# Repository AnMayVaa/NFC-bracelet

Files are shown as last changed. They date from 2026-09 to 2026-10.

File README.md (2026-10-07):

# 🍊 Jeju wish-band: Travel + Connect + Protect

A smart basalt-bead wristband for Jeju visitors. Tap the band on a phone to open a personal travel app with **AI picks** for local food, hidden places and activities. Tap it at wish-band stations to collect stamps and leave a **last-known location** for safety. The **Helping Map** and **SOS** button connect tourists to help, and the admin desk sees everything live.

| Part | What it does |
| :--- | :--- |
| 📱 Tourist app (`/<UID>`) | **For You**: one-tap diet setup, stamp progress strip, live weather card, map + AI picks (diet-safe, weather-aware, boosts local and quiet spots) · **Stamps**: road route map, passport, 4,000 KRW Dongmun Market voucher · **SOS**: hold-to-send SOS, Korean hotlines, your embassy or consulate, Helping Map, help near you · **Me**: any nationality (flag, name in any script), international emergency contact, language (English, 한국어, 中文, 日本語, ไทย) and dark mode |
| 🏢 Admin desk (`/admin`) | Issue and register bands, write NFC tags, SOS queue (acknowledge, dispatch, resolve), station health, live log, evaluation metrics, **Demo control** (load a mock story, play each journey step for one band, clear SOS / stamps / guests, download a backup, delete everything) |
| 📟 `firmware/admin` | ESP32 + PN532 desk reader: reads the tag, writes the tourist link, reports to the admin desk |
| 🍊 `firmware/food` · 🗿 `firmware/place` · 🌊 `firmware/activity` | ESP32 stations (MFRC522 by default, PN532 optional): each tap gives a stamp of that kind |

---

## 1. Run it

```bash
npm install
npm start            # http://localhost:3000
npm test             # core rules: stamps, voucher, diet filter, SOS flow, migration
```

- Tourist app: http://localhost:3000/BEAD_001 (any tag UID works as the path)
- Admin desk: http://localhost:3000/admin, then press **Load full demo story** in Demo control
- Live site: https://smart-nfc-bracelet.vercel.app (Vercel uses `api/index.js`)

To simulate taps without hardware, use **Demo control** on the admin desk (`/admin`).

### Environment variables (all optional)

| Variable | Default | Meaning |
| :--- | :--- | :--- |
| `PUBLIC_URL` | `https://smart-nfc-bracelet.vercel.app` | Base of the link written onto tags |
| `MERCHANT_PIN` | `4000` | PIN the market vendor types to redeem a voucher |
| `STATION_KEY` | empty | If set, ESP32s must send it as `X-Station-Key` (put the same value in `secrets.h`) |
| `ADMIN_PIN` | empty | If set, the admin desk asks for it |
| `DEMO_MODE` | `true` | `false` hides demo tools, Demo control, simulated taps, wipe and restore |
| `UV_OVERRIDE` | empty | Force a UV index (for demos); otherwise live UV from Open-Meteo |
| `WEATHER_OVERRIDE` | empty | Force weather for a demo, e.g. `{"tempC":24,"rainChance":90,"precipMm":3}` |
| `PHOTOS_LIVE` | on | `0` stops the live Wikipedia photo lookup (cards keep their emoji unless photos are bundled) |
| `OSRM_URL` | OpenStreetMap foot router | Routing server for the road route on the Stamps map |
| `SUPABASE_URL` | empty | Your Supabase project URL. With the key below, data lives in Supabase instead of `database.json` |
| `SUPABASE_SERVICE_ROLE_KEY` | empty | Supabase secret key (server only, never in the browser or in git) |

### Database: Supabase (recommended for Vercel)

Without the two Supabase variables the app keeps everything in `database.json` (on Vercel that is `/tmp`, which resets). With them, every wish-band, stamp and SOS alert is saved in Supabase Postgres, shared by all Vercel instances, and you can check it in the Supabase **Table Editor**.

1. Create a free project at [supabase.com](https://supabase.com) (region: Seoul or Singapore).
2. **SQL Editor → New query**, paste [`supabase/schema.sql`](supabase/schema.sql), press **Run**. This creates the `tourists` and `sos_alerts` tables plus read-only views `checkins`, `location_log` and `recommendation_events`.
3. **Project Settings → API**: copy the **Project URL** and the **service_role** (secret) key.
4. **Vercel → smart-nfc-bracelet → Settings → Environment Variables**: add `SUPABASE_URL` and `SUPABASE_SERVICE_ROLE_KEY`, then redeploy. For local runs put them in your shell before `npm start`.
5. Open `/api/health`: it shows `"storage": "supabase"` and `"database": { "ok": true, "tourists": N }` when it is connected, or the Supabase error message if not. On /admin, **Demo control → Load full demo story** fills the tables with 11 demo wish-bands and 3 SOS alerts; the header chip turns green ("Supabase").

Row Level Security is on with no policies, so the public anon key can read nothing; only the server's secret key can. Never commit the secret key (the repo is public).

---

## 2. Project structure

```
lib/
  core.js            business rules (pure functions, unit tested)
  app.js             every API route, shared by both servers
  store.js           Supabase or JSON-file store, schema version + auto-migration
  weather.js         live Jeju weather: UV, temperature, rain, wind (Open-Meteo, cached 15 min)
  route.js           Stamps route along real roads (saved file, OSRM, or straight lines)
  photos.js          real photos for the For You cards (bundled file, else Wikipedia/Commons live)
  data/countries.js  calling codes for every country (names come from the browser in any language)
  data/stations.js   stations, stamp kinds, reward rule, help points, hotlines
  data/catalog.js    places / food / activities the AI picks from
server.js            local server: shared app + static files + WebSocket
api/index.js         Vercel serverless entry (same app)
public/              tourist app (index.html, app.js), admin desk (admin.html, admin.js), shared style.css
firmware/            admin, food, place, activity sketches (+ tools/ RC522 diagnostic)
supabase/schema.sql  tables + views to paste into the Supabase SQL Editor
test/                node --test unit tests
```

### Road route for the Stamps map

The app asks `/api/route`, which uses `lib/data/route.json` if it exists, otherwise OpenStreetMap foot routing (OSRM), otherwise straight lines. To make the demo independent of the public router, run once on a computer with internet and commit the file:

```
npm run build-route
```

Run it again whenever a station moves.

### First use

A new wish-band opens a 3-step setup before the app: **interests** (pick at least one), **health** (how the tourist gets around, diet, other allergy, optional medical notes) and **emergency contact** (nationality plus a phone number in international format). Everything can be changed later in **Me**. Medical notes and mobility are shown to the admin desk on any SOS.

### Photos and links on the For You cards

Each card shows a real photo from Wikimedia Commons with its author and licence, or keeps its emoji if no photo is found. Food items are sample dishes, so their photo shows the dish, not a specific shop. Without setup the server looks the photos up live from Wikipedia. To bundle them in the repo so the demo works offline, run once with internet and commit the result:

```
npm run fetch-photos
```

It saves the images to `public/img/places/`, the credits to `public/img/places/CREDITS.md` and the list to `lib/data/photos.json`. The card's link goes to the official website when the catalog has one (`website`), otherwise to the place on Google Maps; **About** opens the UNESCO or Wikipedia page.

### Place details and today's interests

Tapping a card opens its details: photo, address, why it was picked, **Good to know** and **Check before you go** notes from the official listing, and buttons for the official page (VisitJeju or VisitKorea), directions and the map. The **Today I feel like** chips above the list replace the profile interests for today only (`/api/recommendations?today=food,nature`). Real venues, their source pages and the accessibility notes came from the team's Figma Make mockup research.

### Adding things later

- **New station** (for example a second food stall): add an entry to `lib/data/stations.js` with a new `id` and `kind`, copy `firmware/food` to a new folder, and change `STATION_ID`. The app, admin desk and voucher rule pick it up automatically.
- **New stamp kind**: add it to `STATION_KINDS`. The voucher needs one stamp of every kind listed in `REWARD.requiredKinds`.
- **New language**: add a block to `public/i18n.js` and an entry in `LANGS`. Missing keys fall back to English. The app ships English, Korean, Chinese, Japanese, Thai, French, German, Spanish, Italian, Portuguese and Russian; the last six are machine translations that a native speaker should check.
- **New recommendation**: add an item to `lib/data/catalog.js` (with `interests`, `effort`, `wiki` titles for the photo, and `source`, `address`, `good`, `check` in `EXTRA`). Only add dietary tags that are verified; untagged food is hidden from anyone with a restriction.
- **Database**: set the Supabase variables above. Another database can replace `lib/store.js` as long as it keeps the `refresh/load/save/replace` interface.

### How the AI picks work

`S = N · D · G · M · (0.30·Proximity + 0.20·Rating + 0.15·Weather fit + 0.15·Local & quiet + 0.10·Next stop + 0.10·Interests)`

- **N** removes places at stations the tourist already stamped.
- **D** keeps food only if it carries every diet tag the tourist declared (vegan counts as vegetarian). Unknown allergies fail closed.
- **G** is the bad-weather gate: in rain or strong wind, fully exposed spots drop (×0.6).
- **M** is the mobility gate: for wheelchair users steep or long walks are hidden (×0) and some-walking spots drop (×0.5); for short walks only they drop to ×0.4 and ×0.8.
- **Interests** is 1 when the item matches an interest from the first-use setup, 0 when it doesn't, 0.5 when none are set.
- **Weather fit** = half UV fit, half live rain / wind / heat / cold fit, from Open-Meteo (`lib/weather.js`, no key, cached 15 min). Rain puts caves, museums and markets first; each card says why ("Dry inside, good for rain", "Out of the wind", "Cool spot for a hot day").
- Proximity uses the phone GPS if shared, else the last station tapped.

### API

| Method & path | Caller | Purpose |
| :--- | :--- | :--- |
| `GET /api/config` | web | Stations, kinds, reward, help points, hotlines |
| `GET /api/tourist/:uid` | phone | Profile, stamps, voucher, active SOS (auto-creates new bands) |
| `POST /api/register` | phone / admin | Save profile |
| `POST /api/checkin` | station ESP32 | `{uid, station}` → stamp; replies `duplicate`, `isNewStamp`, `stampsCollected`, `voucherUnlocked` |
| `POST /api/stations/heartbeat` | ESP32 | Station online status for the admin desk |
| `POST /api/admin/scan` | admin ESP32 | Tag read at the desk |
| `GET/POST /api/admin/write-queue` | admin ESP32 / desk | Custom content for the next tag |
| `GET /api/recommendations` | phone | `?uid&category&lat&lng` → UV, advice, ranked picks |
| `POST /api/recommendations/event` | phone | `shown / opened / visited` for the conversion metric |
| `POST /api/location` | phone | Share GPS as last-known location |
| `POST /api/sos` · `/api/sos/:action` | phone / admin | Raise SOS; `acknowledge`, `dispatch`, `resolve`, `cancel` |
| `POST /api/redeem` | phone + merchant | `{uid, pin}` → single-use voucher |
| `GET /api/admin/status` | admin desk | Everything above plus metrics |

Old firmware ids `checkpoint1` / `checkpoint2` still work (they map to `place` / `food`).

---

## 3. Firmware

Each folder is a normal Arduino sketch. Board: **ESP32 Dev Module**, 115200 baud. Libraries: **MFRC522** (GithubCommunity) and **Adafruit PN532**.

1. In each sketch folder, copy `secrets.example.h` to `secrets.h` and fill in Wi-Fi. `secrets.h` is git-ignored.
2. Flash `admin` to the desk ESP32, and `food`, `place`, `activity` to the three stations.

### Wi-Fi (`wifi_setup.h`, same file in every sketch)

- At boot the ESP32 scans and joins the network it **used last** (saved in flash), then tries the other remembered ones, then everything in `WIFI_SSID_LIST` (BUNDAOBUNTAI, OhmPatumwan).
- If Wi-Fi drops it keeps retrying in the background, and tag reading keeps working.
- **Pick a network by hand in the Serial Monitor** (115200, Newline):

  | Command | Does |
  | :--- | :--- |
  | `scan` | list networks in range (★ = known) |
  | `join 2` | join #2 from the list with its saved password |
  | `join 2 mypassword` | join #2 with this password |
  | `join MyWifi,mypassword` | join by name |
  | `saved` / `forget` | show / clear remembered networks |
  | `portal` / `wifi` | open the phone setup page / show status |

- **Phone setup page**: hold **BOOT** while powering on (or type `portal`, or it opens by itself when no known network is found). Join Wi-Fi `WishBand-<station>` with password `wishband123`, then open http://192.168.4.1, pick a network and tap *Connect & remember*.
- Every network that connects is remembered (up to 5), newest first.

Station sounds: two rising beeps = new stamp, fanfare = voucher unlocked, one short beep = already stamped (within 60 s), two quick beeps = offline (the tap is queued and sent when Wi-Fi returns), low buzz = error. The LED blinks while offline.

To use a PN532 at a station instead of an MFRC522, set `#define USE_PN532 1` at the top of the sketch.

### Wiring

**Admin desk: ESP32 + PN532 (I2C).** DIP switches SEL0 = OFF, SEL1 = ON.

| PN532 | ESP32 |
| :--- | :--- |
| VCC | 3V3 (or 5V) |
| GND | GND |
| SDA | GPIO 21 |
| SCL | GPIO 22 |

**Stations: ESP32 + MFRC522 (SPI).** ⚠️ 3.3 V only. Never connect the MFRC522 to 5 V.

| MFRC522 | ESP32 |
| :--- | :--- |
| 3.3V | 3V3 |
| RST | GPIO 22 |
| GND | GND |
| MISO | GPIO 19 |
| MOSI | GPIO 23 |
| SCK | GPIO 18 |
| SDA (SS) | GPIO 5 |

Buzzer (+) → GPIO 4, LED (+) → GPIO 2 on every board.

Reader not found? Flash `firmware/tools/test_rc522_diagnostic` first.

---

## 4. Critical Real-World Limitations & How to Overcome Them

When building physical prototypes with basalt stones and NFC, you must be aware of several physical and electronic constraints:

### 1. Basalt Stone & Mineral RF Attenuation
- **The Issue**: Genuine Jeju basalt is an igneous volcanic rock that naturally contains iron oxides, titanium (titanomagnetite), and magnesium. Placing an NFC tag directly flush against dense volcanic rock without insulation can detune the 13.56 MHz antenna coil, causing degraded read range or failed reads.
- **The Solution for AuraBeads**:
  - Always encase the NFC tag in a thin barrier of **clear epoxy casting resin or dielectric silicone** before setting it into the basalt bead centerpiece.
  - Keep the tag oriented towards the outer face of the bracelet (facing away from the wrist/stone mass).

### 2. Read Range vs. Tag Size
- **The Issue**: Small coin tags (20mm–25mm diameter) have smaller antenna surface areas, providing an effective read distance of **1.5 cm to 3.5 cm**. They will not read from several inches away.
- **The Solution**:
  - Design the station touchpoints with clear visual targets (e.g. an etched Dol Hareubang circular target on the wooden box) so users know to tap directly against the reader surface.

### 3. iOS vs. Android NFC Quirks
- **iPhone (Apple iOS)**:
  - Background NFC Tag Reading is supported on **iPhone XS, XR, 11, 12, 13, 14, 15, 16+**.
  - The iPhone screen **must be on and unlocked** for background reading to trigger.
  - The NFC antenna on iPhones is located at the **very top edge** of the phone.
  - If held too close while Apple Pay is activated, the payment prompt might appear. A cleanly formatted NDEF URL record resolves this.
- **Android**:
  - NFC antenna placement varies: Samsung Galaxy devices usually place the coil in the **center back**, while Google Pixel devices place it near the **top camera visor**.

### 4. Conference Wi-Fi & Captive Portals
- **The Issue**: University and conference Wi-Fi networks (such as hotel or venue networks at JTU 2026) frequently use **Captive Portals** (where you must open a browser to agree to terms) or enable **AP Isolation** (preventing ESP32s and phones from talking to each other).
- **The Solution**:
  - For your live competition pitch, **create a Mobile Hotspot from your smartphone or portable 4G router**.
  - Connect your laptop and all your ESP32s to this hotspot. This guarantees 100% stable communication unaffected by venue Wi-Fi restrictions!

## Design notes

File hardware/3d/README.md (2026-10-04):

# Jeju wish-band: device enclosures (3D)

Printable 3D enclosures for the two Jeju wish-band devices: the **admin desk unit** used by staff to register bands, and the **check-in station** used at food, place and activity stops. The folder also has renders and dimensioned drawings.

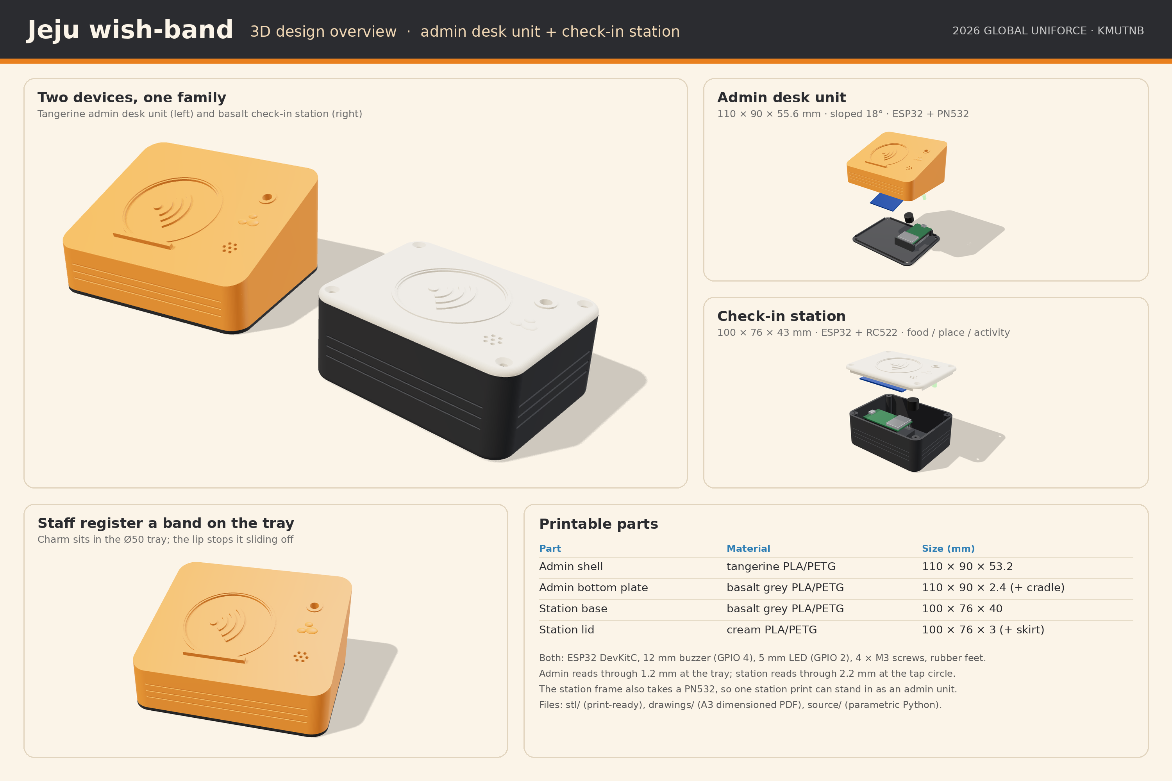
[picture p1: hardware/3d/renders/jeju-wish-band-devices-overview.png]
overview


## What is here

| Folder | Contents |
|---|---|
| `stl/` | Print-ready STL files, already placed the right way up for printing. `scene.json` lists every size and volume. |
| `glb/` | Coloured, assembled models (`admin-desk-unit.glb`, `checkin-station.glb`) that open in phone and desktop 3D viewers, such as Windows 3D Viewer, macOS Quick Look or gltf-viewer.donmccurdy.com. |
| `drawings/` | `jeju-wish-band-device-drawings.pdf` has two A3 sheets at 1:1: sheet 1 is the admin desk unit and sheet 2 is the check-in station. Print at 100 % and the sizes are true. PNG copies of each sheet are included. |
| `renders/` | The overview poster (PNG + PDF), both devices together, and each device whole and exploded. |
| `source/` | Parametric source. `models.py` builds the STLs and `drawing.py` makes the drawings. `render.html`, `render_shots.mjs` and `compose_overview.py` make the renders. |

## Devices

| Device | Firmware | Parts to print | Outside size (mm) |
|---|---|---|---|
| Admin desk unit | `firmware/admin` (ESP32 + PN532 over I2C) | `admin_shell.stl` (tangerine), `admin_bottom_plate.stl` (basalt grey) | 110 × 90 × 55.6, top sloped 18° |
| Check-in station | `firmware/food`, `place`, `activity` (ESP32 + RC522) | `station_base.stl` (basalt grey), `station_lid.stl` (cream) | 100 × 76 × 43 |

Both devices also need an ESP32 DevKitC, a 12 mm buzzer on GPIO 4, a 5 mm LED on GPIO 2, four M3 self-tapping screws and four Ø10 rubber feet.

**Admin desk unit.** Staff place the wristband charm in the Ø50 tray on the sloped top, and a small lip stops it sliding off. The PN532 is held in a frame under the tray and reads through 1.2 mm of plastic. The ESP32 sits in a cradle on the bottom plate with its USB port at the back wall. The shell is printed lying on its sloped top, so it needs no supports.

**Check-in station.** Tourists tap the charm on the Ø46 circle on the lid. The RC522 is held in a frame under the lid and reads through 2.2 mm of plastic. The ESP32 sits in a floor cradle with its USB port at the left wall.

**Can one enclosure do both jobs?** Yes. The reader frame in the station lid also takes a PN532, so a printed station can serve as the admin unit with no changes. The admin unit is a separate design because a sloped desk tray is easier for staff to use.

## Assembly

1. Push the buzzer and LED into their tubes under the top.
2. Stick the reader board into its frame with foam tape.
3. Clip the ESP32 into its cradle with the USB port facing the opening.
4. Close the enclosure with four M3 screws and add the rubber feet.

## Assumed sizes (check yours before printing)

- ESP32 DevKitC V4: 54.4 × 27.9 mm, header pins pointing down
- RC522: 60 × 40 mm
- PN532 V3: 42.7 × 40.4 mm
- Buzzer: Ø12 × 9.5 mm
- LED: 5 mm

## Changing the design

Every size is in `PARAMS` at the top of `source/models.py`. Change a number, then rebuild:

```bash
pip install manifold3d trimesh numpy matplotlib shapely networkx
cd source
python3 models.py     # writes ../stl/*.stl
python3 drawing.py    # writes ../drawings/
```

To rebuild the renders:

1. In `source/`, run `npm i three playwright && npx playwright install chromium`.
2. Copy `../stl/scene.json` into `_render_parts/`.
3. Run `node render_shots.mjs family admin admin_exploded station station_exploded`.
4. Run `python3 compose_overview.py`.

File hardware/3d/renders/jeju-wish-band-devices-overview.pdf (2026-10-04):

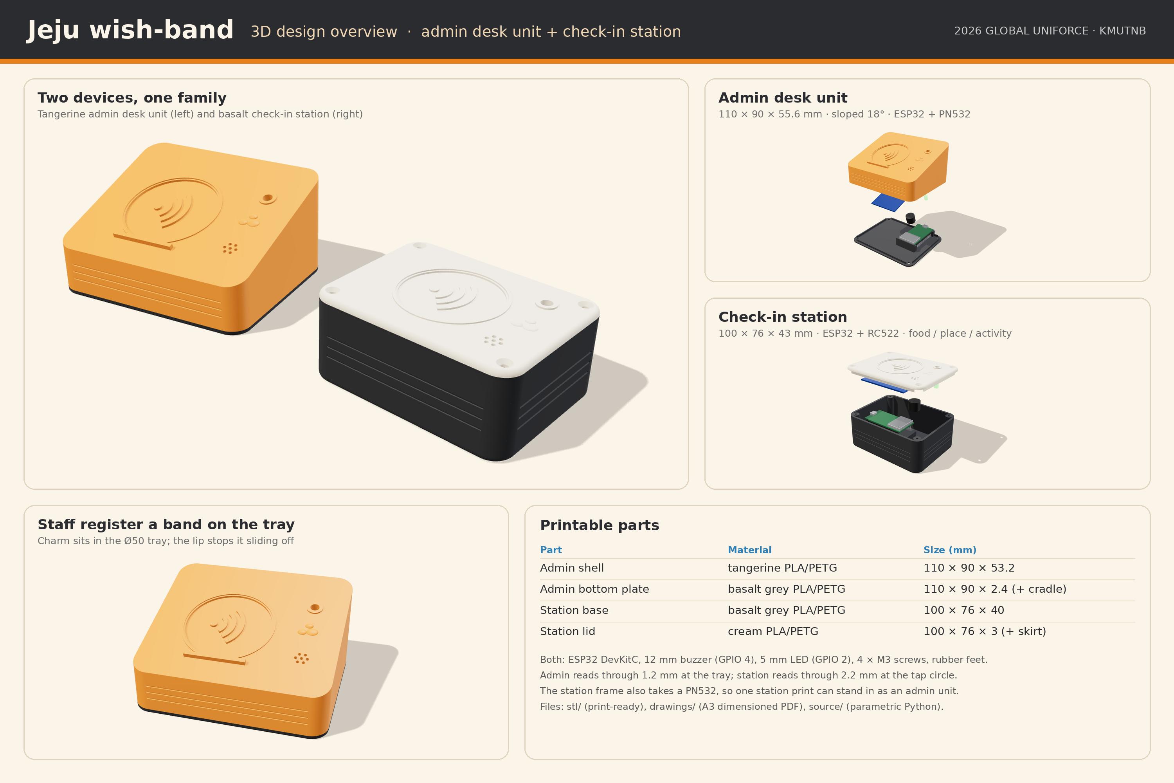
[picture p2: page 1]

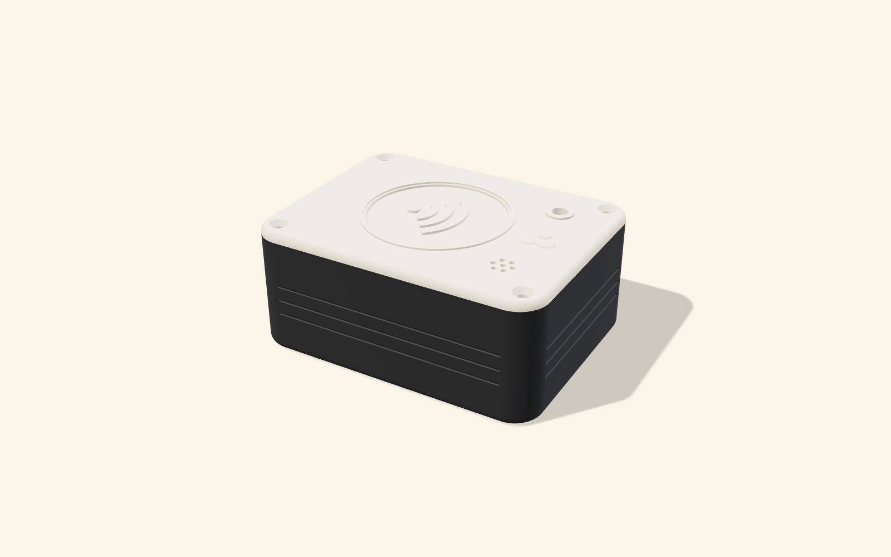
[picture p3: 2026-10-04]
hardware/3d/renders/render-station.png

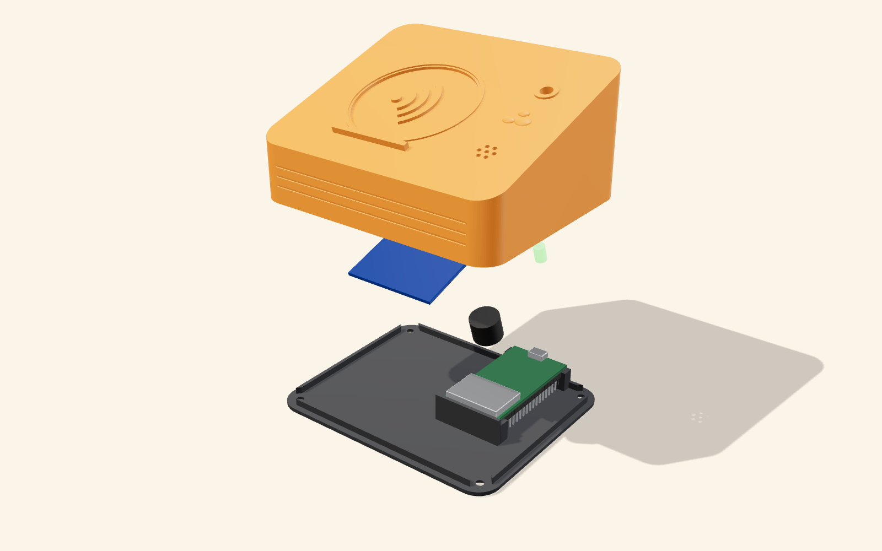
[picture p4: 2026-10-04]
hardware/3d/renders/render-admin-exploded.png

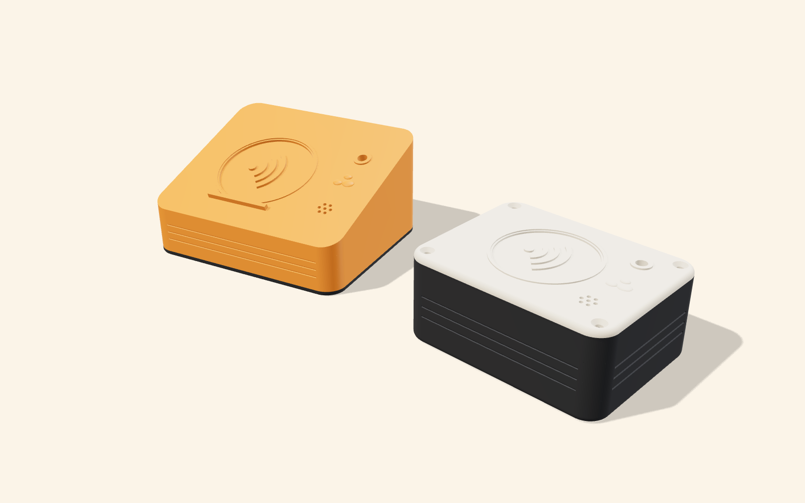
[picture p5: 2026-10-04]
hardware/3d/renders/render-both-devices.png

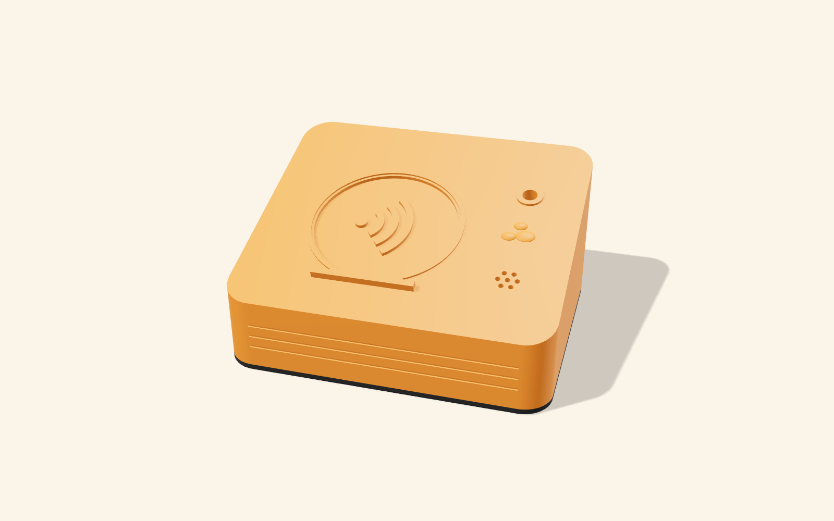
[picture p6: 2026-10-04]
hardware/3d/renders/render-admin.png

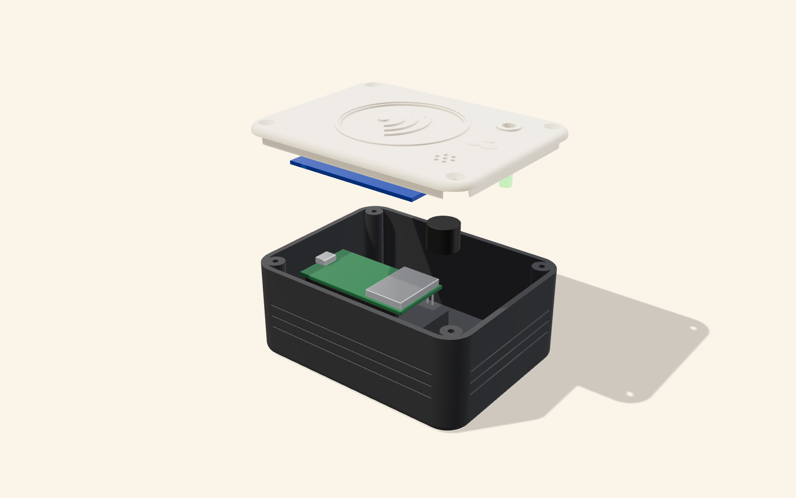
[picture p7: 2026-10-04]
hardware/3d/renders/render-station-exploded.png

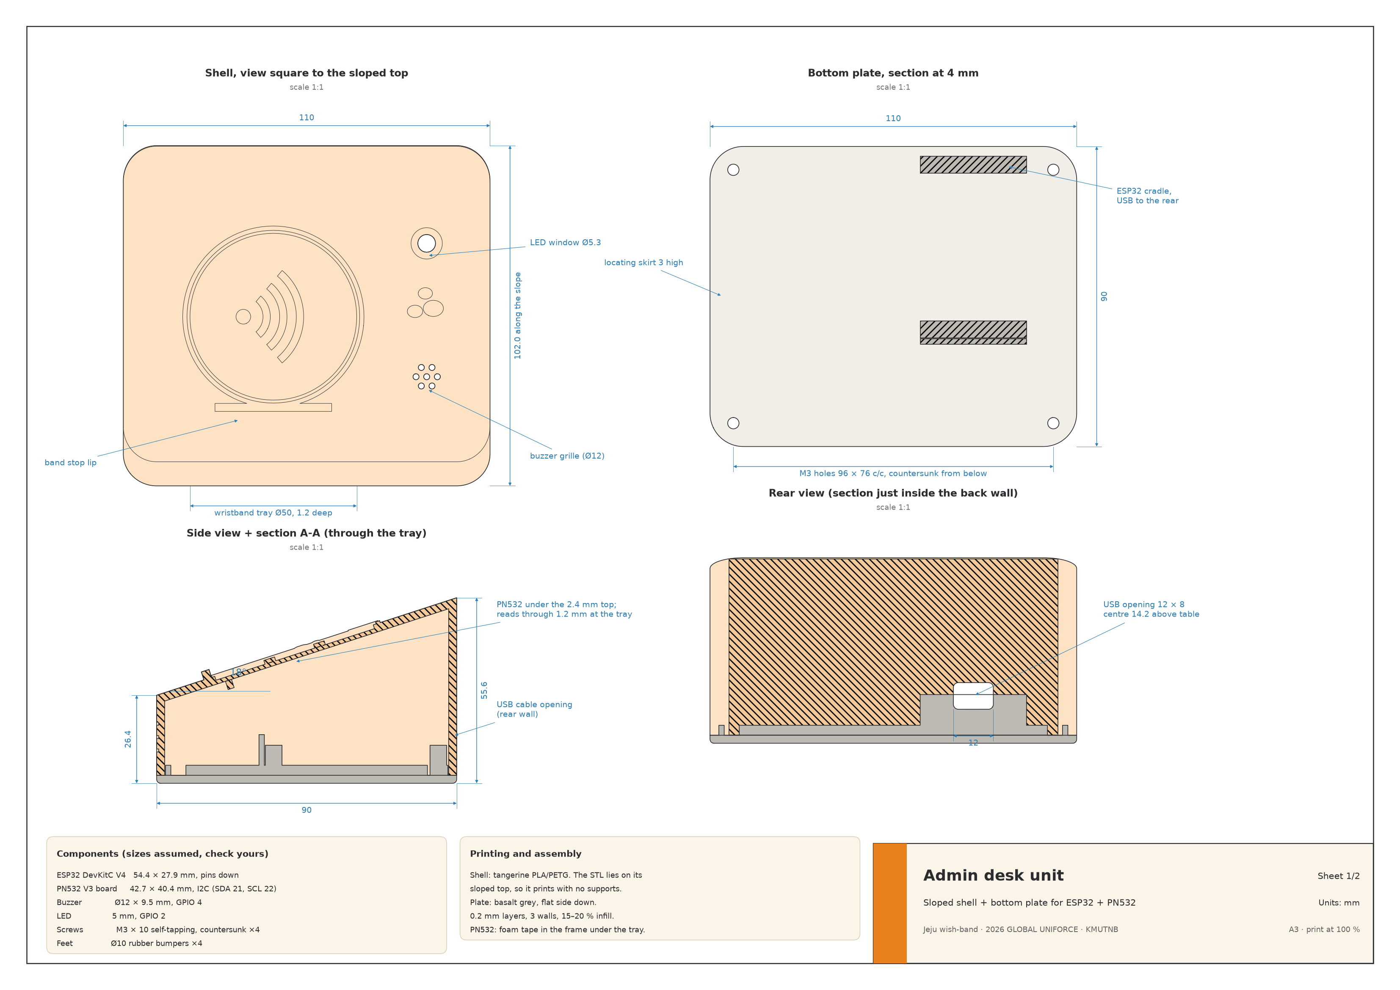
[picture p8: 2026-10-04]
hardware/3d/drawings/sheet1-admin-desk-unit.png

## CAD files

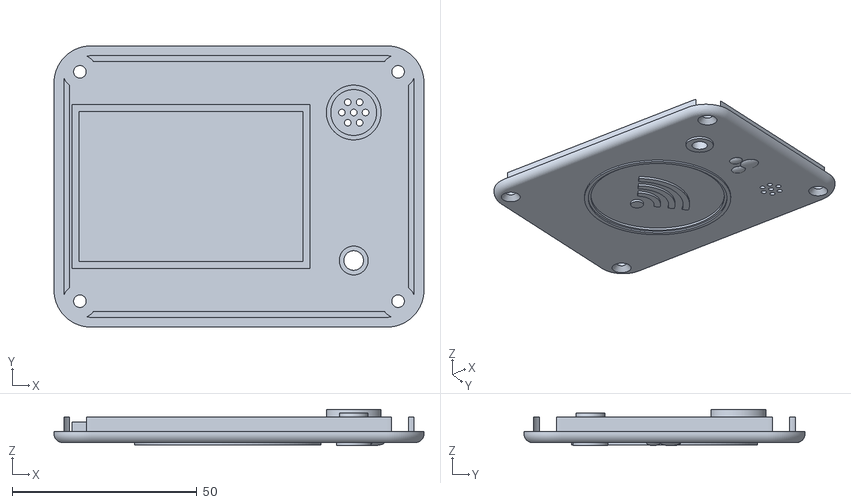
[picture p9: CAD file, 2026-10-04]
hardware/3d/stl/station_lid.stl
100.0 x 76.0 x 9.80

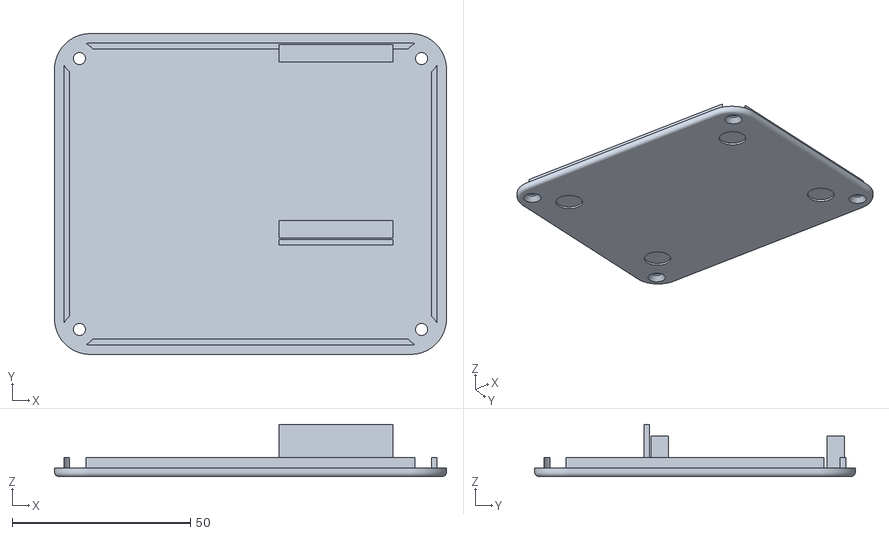
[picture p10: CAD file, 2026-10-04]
hardware/3d/stl/admin_bottom_plate.stl
110.0 x 90.0 x 14.6

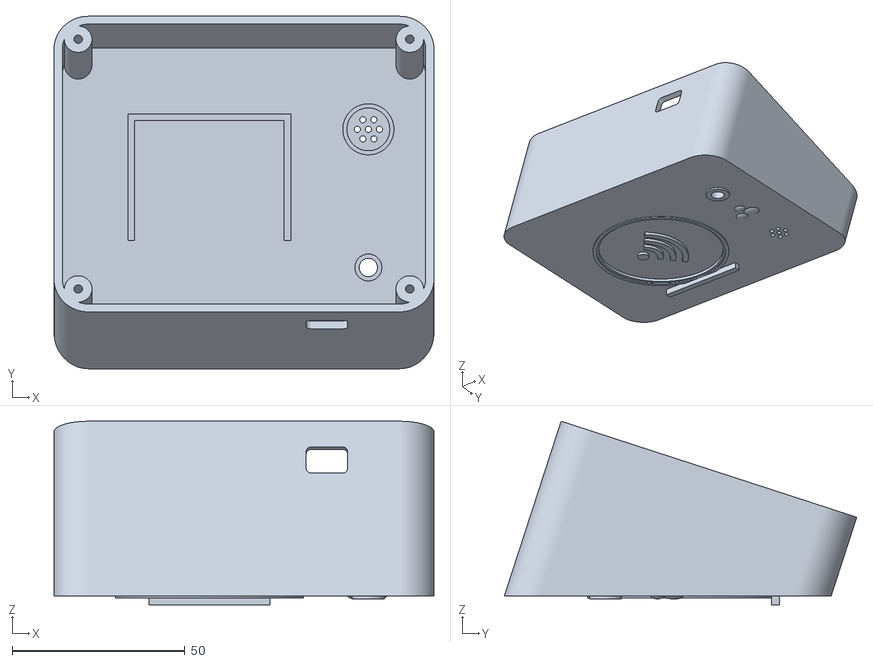
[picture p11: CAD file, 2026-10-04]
hardware/3d/stl/admin_shell.stl
110.0 x 102.0 x 53.1

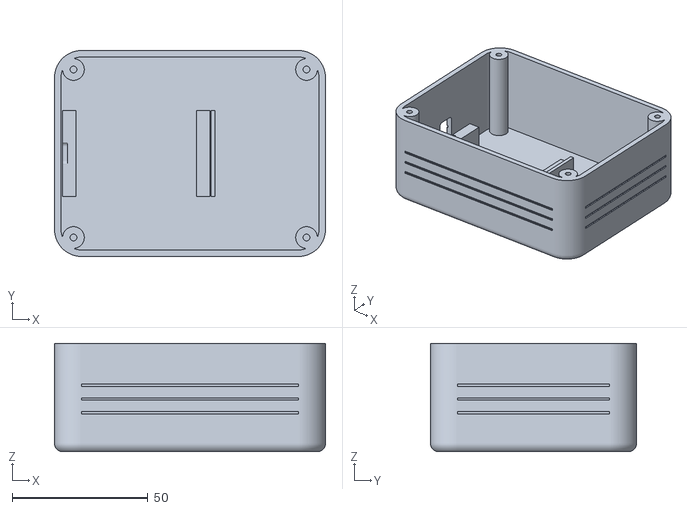
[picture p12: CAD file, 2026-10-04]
hardware/3d/stl/station_base.stl
100.0 x 76.0 x 40.0

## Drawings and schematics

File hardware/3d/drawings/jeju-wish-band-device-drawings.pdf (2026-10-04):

## Shell, view square to the sloped top

## Bottom plate, section at 4 mm

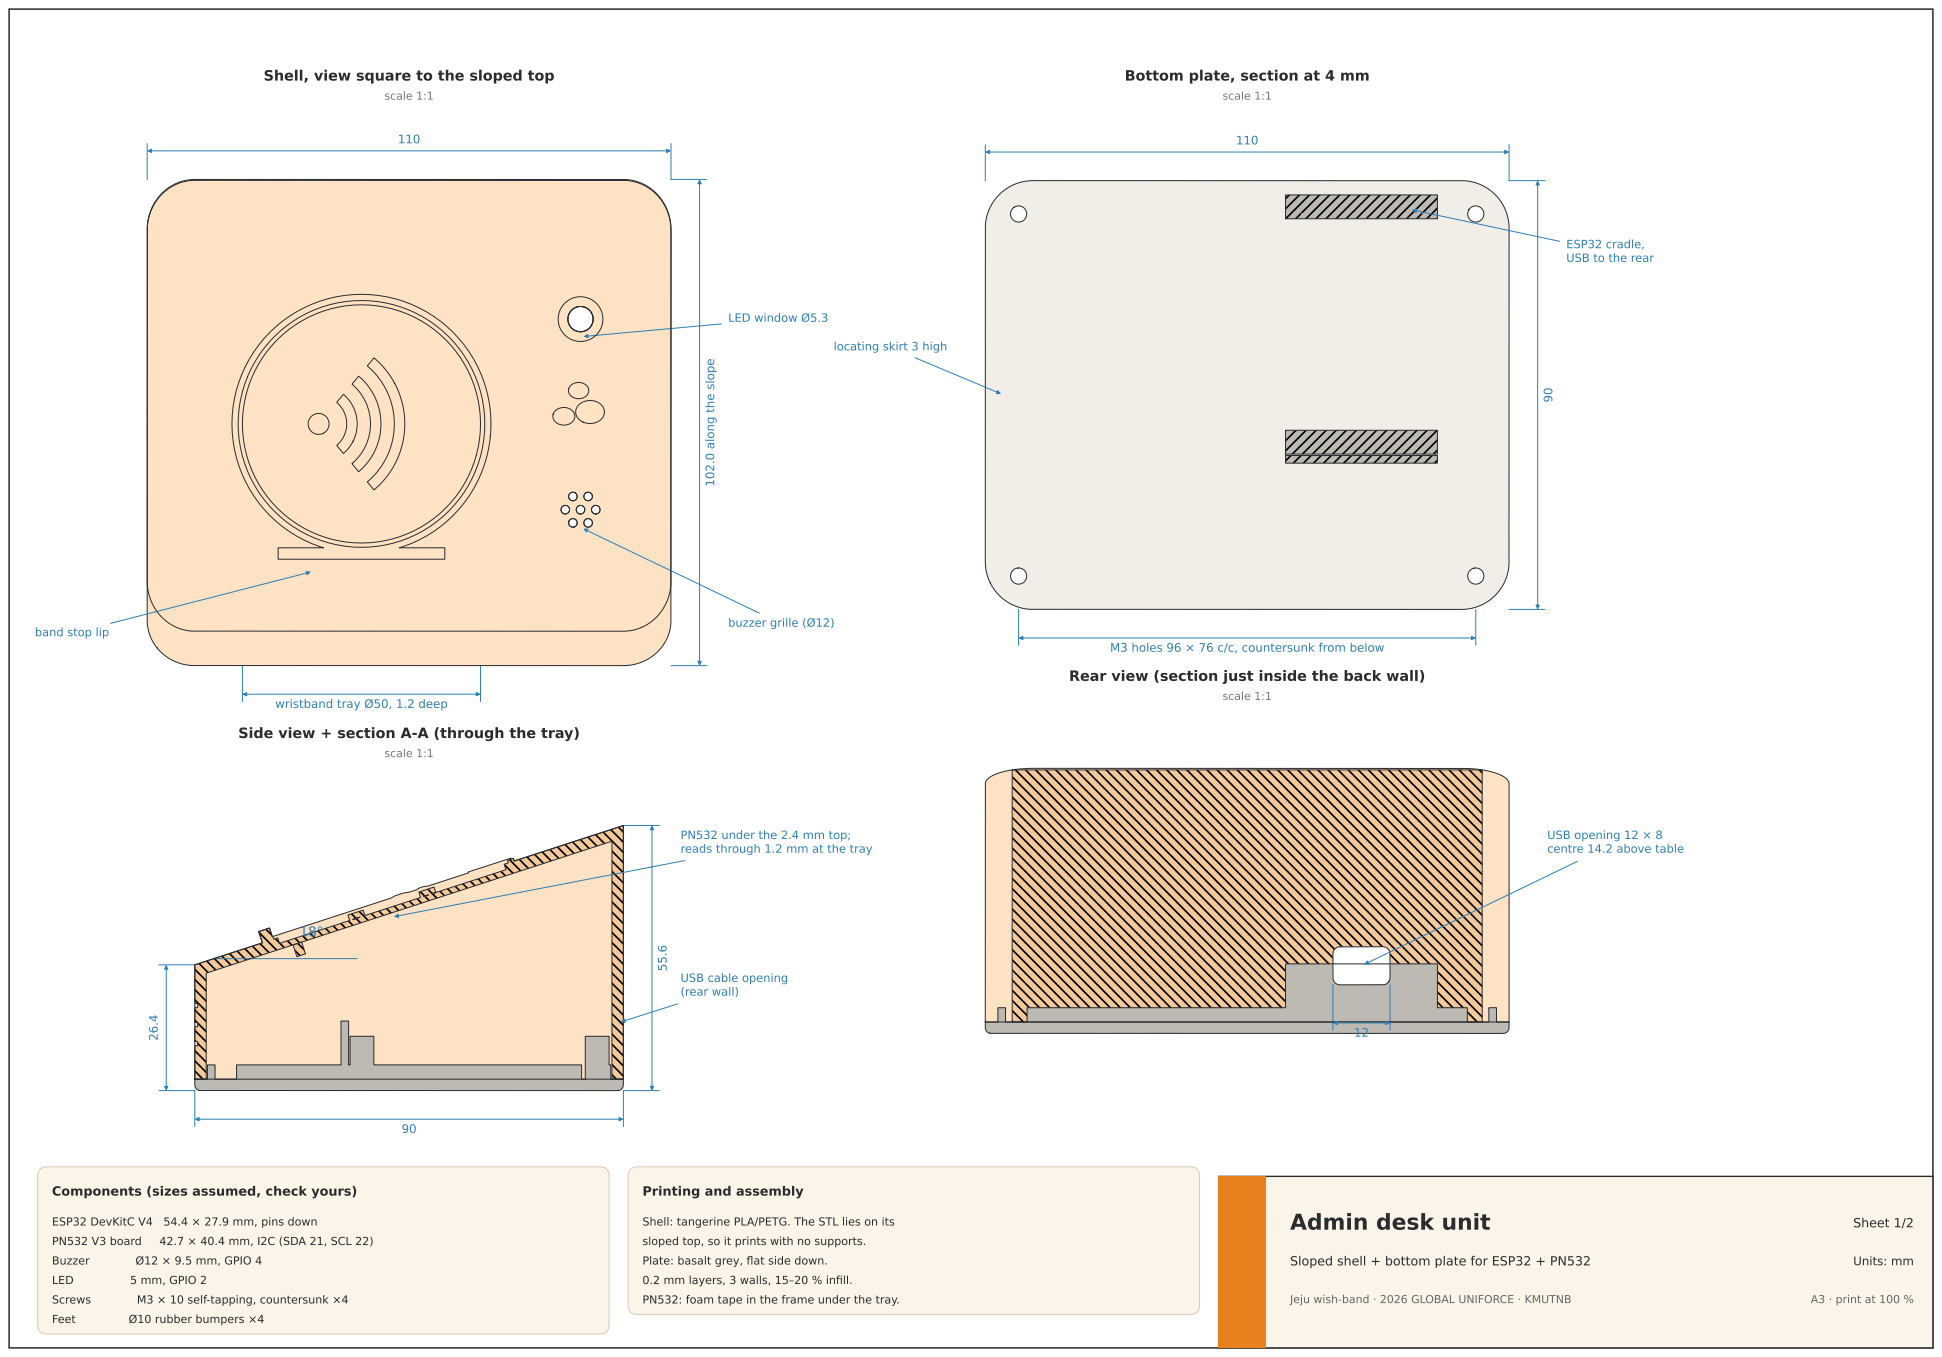
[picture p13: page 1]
Sheet 1/2; Units: mm; A3 · print at 100 %; scale 1:1; buzzer grille (Ø12); LED window Ø5.3; PN532 V3 board; 42.7 × 40.4 mm, I2C (SDA 21, SCL 22); Buzzer; Ø12 × 9.5 mm, GPIO 4; LED; 5 mm, GPIO 2; Screws; M3 × 10 self-tapping, countersunk ×4; Feet; Ø10 rubber bumpers ×4

ESP32 cradle,
USB to the rear

locating skirt 3 high

102.0 along the slope

band stop lip

M3 holes 96 × 76 c/c, countersunk from below

Rear view (section just inside the back wall)

wristband tray Ø50, 1.2 deep

Side view + section A-A (through the tray)

PN532 under the 2.4 mm top;
reads through 1.2 mm at the tray

USB opening 12 × 8
centre 14.2 above table

USB cable opening
(rear wall)

Components (sizes assumed, check yours)

Printing and assembly

Admin desk unit

ESP32 DevKitC V4 54.4 × 27.9 mm, pins down

Shell: tangerine PLA/PETG. The STL lies on its

sloped top, so it prints with no supports.
Plate: basalt grey, flat side down.

Sloped shell + bottom plate for ESP32 + PN532

0.2 mm layers, 3 walls, 15–20 % infill.

PN532: foam tape in the frame under the tray.

Jeju wish-band · 2026 GLOBAL UNIFORCE · KMUTNB

## Base, section at 8 mm (top view)

## Lid, top view

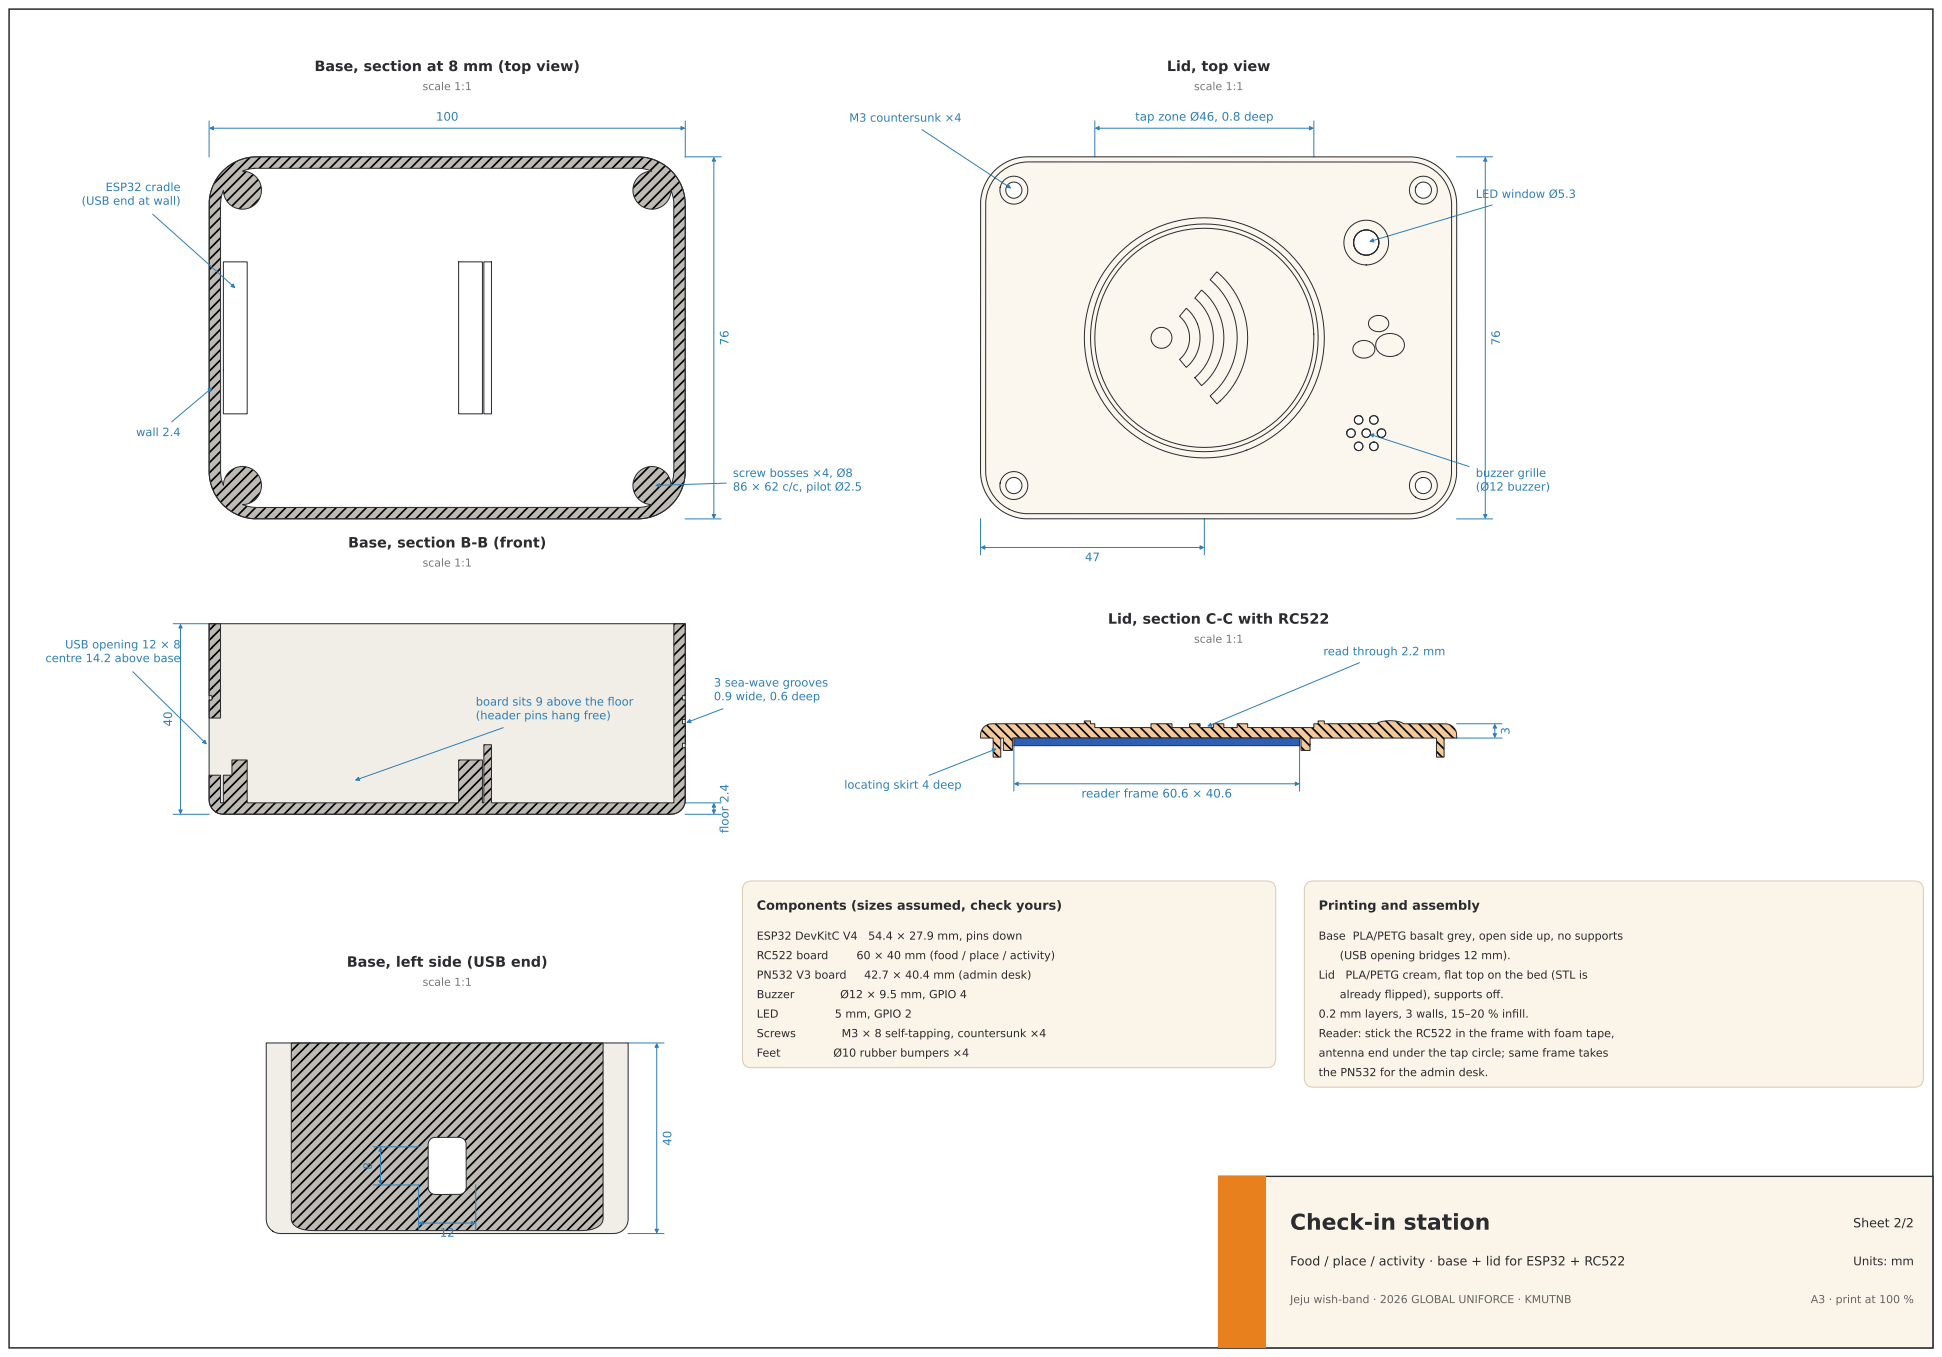
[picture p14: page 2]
Sheet 2/2; Units: mm; A3 · print at 100 %; scale 1:1; screw bosses ×4, Ø8 86 × 62 c/c, pilot Ø2.5; wall 2.4; floor 2.4; buzzer grille (Ø12 buzzer); LED window Ø5.3; M3 countersunk ×4; reader frame 60.6 × 40.6; RC522 board; 60 × 40 mm (food / place / activity); PN532 V3 board; 42.7 × 40.4 mm (admin desk); Buzzer; Ø12 × 9.5 mm, GPIO 4; LED; 5 mm, GPIO 2; Screws; M3 × 8 self-tapping, countersunk ×4; Feet; Ø10 rubber bumpers ×4

tap zone Ø46, 0.8 deep

ESP32 cradle
(USB end at wall)

Base, section B-B (front)

Lid, section C-C with RC522

USB opening 12 × 8
centre 14.2 above base

read through 2.2 mm

3 sea-wave grooves
0.9 wide, 0.6 deep

board sits 9 above the floor
(header pins hang free)

locating skirt 4 deep

Components (sizes assumed, check yours)

Printing and assembly

ESP32 DevKitC V4 54.4 × 27.9 mm, pins down

Base PLA/PETG basalt grey, open side up, no supports

Base, left side (USB end)

(USB opening bridges 12 mm).
Lid PLA/PETG cream, flat top on the bed (STL is

already flipped), supports off.

0.2 mm layers, 3 walls, 15–20 % infill.

Reader: stick the RC522 in the frame with foam tape,

antenna end under the tap circle; same frame takes

the PN532 for the admin desk.

Check-in station

Food / place / activity · base + lid for ESP32 + RC522

Jeju wish-band · 2026 GLOBAL UNIFORCE · KMUTNB

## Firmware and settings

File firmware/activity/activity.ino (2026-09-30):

/*
  =============================================================================
  🌋 Jeju wish-band — Activity Station
  Board: ESP32 Dev Module     Reader: MFRC522 (SPI)  or  PN532 (I2C)
  =============================================================================

  What it does
    Tap a wish-band -> POST /api/checkin {uid, station:"activity"} -> the tourist
    gets a activity stamp. Collect food + place + activity to unlock the voucher.

  Feedback
    New stamp        : two rising beeps
    Voucher unlocked : four-note fanfare
    Already stamped  : one short beep (tapped again within 60 s)
    Offline          : two quick beeps (tap is queued and sent when Wi-Fi is back)
    Error            : low buzz

  Wi-Fi (see wifi_setup.h)
    Goes back to the network used last time, then tries the others it knows
    (secrets.h: BUNDAOBUNTAI, OhmPatumwan). Reconnects by itself if the hotspot drops.
    Pick one by hand: type "scan" then "join 2" in the Serial Monitor, or hold BOOT
    at power-on and use the phone setup page (Wi-Fi "WishBand-activity", pw wishband123).

  Setup
    1. Copy secrets.example.h to secrets.h in this folder and fill it in.
    2. Libraries: "MFRC522" by GithubCommunity (or "Adafruit PN532" if USE_PN532 = 1).
    3. Board: ESP32 Dev Module, 115200 baud.

  MFRC522 wiring (3.3 V ONLY, never 5 V)     PN532 wiring (DIP: SEL0=OFF, SEL1=ON for I2C)
    3.3V -> 3V3    RST  -> GPIO 22             VCC -> 3V3 / 5V
    GND  -> GND    MISO -> GPIO 19             GND -> GND
    SCK  -> GPIO 18 MOSI -> GPIO 23            SDA -> GPIO 21
    SDA/SS -> GPIO 5                           SCL -> GPIO 22
  Buzzer (+) -> GPIO 4    LED (+) -> GPIO 2 (built-in LED on most boards)
  =============================================================================
*/

// ---------------------------------------------------------------- station
#define STATION_ID    "activity"        // must match lib/data/stations.js on the server
#define STATION_NAME  "Haenyeo Museum"
#define FW_VERSION    "2.0.0"

// 0 = MFRC522 (SPI), 1 = PN532 (I2C)
#define USE_PN532 0

// ---------------------------------------------------------------- includes
#include <WiFi.h>
#include <HTTPClient.h>
#include <WiFiClientSecure.h>

#if __has_include("secrets.h")
  #include "secrets.h"
#else
  #warning "secrets.h not found: using secrets.example.h (copy it to secrets.h and fill in your Wi-Fi)"
  #include "secrets.example.h"
#endif
#include "wifi_setup.h"

#if USE_PN532
  #include <Wire.h>
  #include <Adafruit_PN532.h>
  #define SDA_PIN 21
  #define SCL_PIN 22
  Adafruit_PN532 nfc(SDA_PIN, SCL_PIN);
#else
  #include <SPI.h>
  #include <MFRC522.h>
  #define SS_PIN  5
  #define RST_PIN 22
  MFRC522 rfid(SS_PIN, RST_PIN);
#endif

#define BUZZER_PIN 4
#define LED_PIN    2

// ---------------------------------------------------------------- state
const char* WIFI_SSIDS[] = WIFI_SSID_LIST;
const int WIFI_COUNT = sizeof(WIFI_SSIDS) / sizeof(WIFI_SSIDS[0]);

String lastUid = "";
unsigned long lastTapAt = 0;
const unsigned long LOCAL_DEBOUNCE_MS = 2500;   // ignore a tag held on the reader

const int QUEUE_MAX = 20;                       // taps kept while offline
String pending[QUEUE_MAX];
int pendingCount = 0;

unsigned long lastFlush = 0;
unsigned long lastHeartbeat = 0;
const unsigned long HEARTBEAT_MS = 60000;

// ---------------------------------------------------------------- sounds
void beep(int freq, int ms) { tone(BUZZER_PIN, freq, ms); delay(ms + 20); }

void soundStamp()   { digitalWrite(LED_PIN, HIGH); beep(2200, 110); beep(2900, 170); digitalWrite(LED_PIN, LOW); }
void soundVoucher() { digitalWrite(LED_PIN, HIGH); beep(2000, 100); beep(2400, 100); beep(2800, 100); beep(3400, 280); digitalWrite(LED_PIN, LOW); }
void soundRepeat()  { digitalWrite(LED_PIN, HIGH); beep(2600, 70); digitalWrite(LED_PIN, LOW); }
void soundQueued()  { digitalWrite(LED_PIN, HIGH); beep(2400, 60); beep(2400, 60); digitalWrite(LED_PIN, LOW); }
void soundError()   { digitalWrite(LED_PIN, HIGH); beep(700, 380); digitalWrite(LED_PIN, LOW); }

// ---------------------------------------------------------------- Wi-Fi
void setupWifi() {
  for (int i = 0; i < WIFI_COUNT; i++) WifiSetup::addBuiltIn(WIFI_SSIDS[i], WIFI_PASSWORD);
  WifiSetup::begin("WishBand-" STATION_ID);
}

bool ensureWifi() { return WifiSetup::loop(); }

void handleSerial() {
  if (!Serial.available()) return;
  String cmd = Serial.readStringUntil('\n');
  if (!WifiSetup::handleCommand(cmd) && cmd.length() > 1)
    Serial.println("Commands: scan | join <n> [password] | join Name,password | saved | forget | portal | wifi");
}

// ---------------------------------------------------------------- HTTP
int postJson(const String& path, const String& body, String& response) {
  String url = String(SERVER_URL) + path;
  HTTPClient http;
  WiFiClientSecure secure;
  if (url.startsWith("https://")) { secure.setInsecure(); http.begin(secure, url); }
  else { http.begin(url); }
  http.setTimeout(6000);
  http.addHeader("Content-Type", "application/json");
  if (strlen(STATION_KEY) > 0) http.addHeader("X-Station-Key", STATION_KEY);
  int code = http.POST(body);
  response = code > 0 ? http.getString() : http.errorToString(code);
  http.end();
  return code;
}

// Sends one tap. Returns false if it should be retried later.
bool sendCheckin(const String& uid, bool live) {
  String body = String("{\"uid\":\"") + uid + "\",\"station\":\"" STATION_ID "\",\"ip\":\"" +
                WiFi.localIP().toString() + "\",\"rssi\":" + String(WiFi.RSSI()) + "}";
  String res;
  int code = postJson("/api/checkin", body, res);
  Serial.printf("📡 [%d] %s\n", code, res.c_str());

  if (code == 200) {
    if (!live) return true;  // replayed from the queue: stay quiet
    if (res.indexOf("\"voucherUnlocked\":true") >= 0) { Serial.println("🎉 Voucher unlocked!"); soundVoucher(); }
    else if (res.indexOf("\"duplicate\":true") >= 0) { Serial.println("↺ Already stamped just now"); soundRepeat(); }
    else { Serial.println("🗿 Stamp saved"); soundStamp(); }
    return true;
  }
  if (code >= 400 && code < 500) {   // server said no (bad key, unknown station): don't retry
    if (live) soundError();
    return true;
  }
  if (live) soundError();
  return false;
}

void queueTap(const String& uid) {
  if (pendingCount < QUEUE_MAX) pending[pendingCount++] = uid;
  Serial.printf("🕒 Queued %s (%d waiting)\n", uid.c_str(), pendingCount);
}

void flushQueue() {
  while (pendingCount > 0 && WiFi.status() == WL_CONNECTED) {
    if (!sendCheckin(pending[0], false)) return;
    for (int i = 1; i < pendingCount; i++) pending[i - 1] = pending[i];
    pendingCount--;
  }
}

void sendHeartbeat() {
  String body = String("{\"station\":\"" STATION_ID "\",\"fw\":\"" FW_VERSION "\",\"ssid\":\"") + WiFi.SSID() +
                "\",\"ip\":\"" + WiFi.localIP().toString() + "\",\"rssi\":" + String(WiFi.RSSI()) + "}";
  String res;
  postJson("/api/stations/heartbeat", body, res);
}

// ---------------------------------------------------------------- reader
void setupReader() {
#if USE_PN532
  Wire.begin(SDA_PIN, SCL_PIN);
  nfc.begin();
  uint32_t ver = nfc.getFirmwareVersion();
  if (!ver) {
    Serial.println("❌ PN532 not found. Check DIP switches (I2C) and SDA=21 / SCL=22.");
    while (true) { soundError(); delay(2000); }
  }
  Serial.printf("✅ PN532 firmware %d.%d\n", (ver >> 16) & 0xFF, (ver >> 8) & 0xFF);
  nfc.SAMConfig();
#else
  pinMode(RST_PIN, OUTPUT);
  digitalWrite(RST_PIN, LOW);  delay(10);
  digitalWrite(RST_PIN, HIGH); delay(50);
  SPI.begin(18, 19, 23, SS_PIN);
  SPI.setFrequency(2000000);
  rfid.PCD_Init();
  rfid.PCD_AntennaOn();
  rfid.PCD_SetAntennaGain(rfid.RxGain_max);   // helps with small NFC stickers
  byte v = rfid.PCD_ReadRegister(rfid.VersionReg);
  if (v == 0x00 || v == 0xFF) {
    Serial.println("❌ MFRC522 not responding. Check 3.3 V power and SDA -> GPIO 5.");
    while (true) { soundError(); delay(2000); }
  }
  Serial.printf("✅ MFRC522 online (version 0x%02X)\n", v);
#endif
}

// Returns the tag UID as HEX, or "" when no tag is present.
String readTag() {
#if USE_PN532
  uint8_t uid[7] = {0};
  uint8_t len = 0;
  if (!nfc.readPassiveTargetID(PN532_MIFARE_ISO14443A, uid, &len, 100)) return "";
  String s = "";
  for (uint8_t i = 0; i < len; i++) { if (uid[i] < 0x10) s += "0"; s += String(uid[i], HEX); }
#else
  if (!rfid.PICC_IsNewCardPresent() || !rfid.PICC_ReadCardSerial()) return "";
  String s = "";
  for (byte i = 0; i < rfid.uid.size; i++) { if (rfid.uid.uidByte[i] < 0x10) s += "0"; s += String(rfid.uid.uidByte[i], HEX); }
  rfid.PICC_HaltA();
  rfid.PCD_StopCrypto1();
#endif
  s.toUpperCase();
  return s;
}

// ---------------------------------------------------------------- main
void setup() {
  Serial.begin(115200);
  delay(600);
  pinMode(BUZZER_PIN, OUTPUT);
  pinMode(LED_PIN, OUTPUT);
  Serial.println("\n==============================================");
  Serial.println("🌋 Jeju wish-band · " STATION_NAME);
  Serial.println("   station id: " STATION_ID "   fw " FW_VERSION);
  Serial.println("==============================================");

  setupReader();
  setupWifi();
  if (WiFi.status() == WL_CONNECTED) { soundStamp(); sendHeartbeat(); lastHeartbeat = millis(); }
  Serial.println("\n👉 Ready. Tap a wish-band! (type \"help\" for Wi-Fi commands)\n");
}

void loop() {
  handleSerial();
  bool online = ensureWifi();

  // LED breathes slowly while offline so staff can see it
  if (!online) digitalWrite(LED_PIN, (millis() / 500) % 2);
  else if (pendingCount == 0) digitalWrite(LED_PIN, LOW);

  String uid = readTag();
  if (uid.length() > 0 && (uid != lastUid || millis() - lastTapAt > LOCAL_DEBOUNCE_MS)) {
    lastUid = uid;
    lastTapAt = millis();
    Serial.printf("\n📍 Tap: %s\n", uid.c_str());
    if (!online) { queueTap(uid); soundQueued(); }
    else if (!sendCheckin(uid, true)) queueTap(uid);
  }

  if (online) {
    if (pendingCount > 0 && millis() - lastFlush > 10000) { lastFlush = millis(); flushQueue(); }
    if (millis() - lastHeartbeat > HEARTBEAT_MS) { sendHeartbeat(); lastHeartbeat = millis(); }
  }
  delay(60);
}

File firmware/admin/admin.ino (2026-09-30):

/*
  =============================================================================
  🌋 Jeju wish-band — Admin Desk Station
  Board: ESP32 Dev Module     Reader: PN532 (I2C)
  =============================================================================

  What it does (airport / hotel desk)
    1. Staff taps a new wish-band on the PN532.
    2. The ESP32 asks the server what to write (GET /api/admin/write-queue):
         - a custom text/URL queued from the Admin web page, or
         - the default tourist link  <SERVER>/<UID>
    3. It burns that NDEF record onto the NTAG sticker (skipped if already there),
       reads it back to verify, and reports it (POST /api/admin/scan).
    4. The Admin web page shows the UID so staff can register the tourist.

  Serial Monitor commands (115200 baud)
    W:<text or url>   queue a one-off write for the next tag
    scan / join <n>   pick a Wi-Fi network by hand (see wifi_setup.h, "help" lists all)

  Wi-Fi (see wifi_setup.h)
    Goes back to the network used last time, then tries the others it knows
    (secrets.h: BUNDAOBUNTAI, OhmPatumwan). Reconnects by itself if the hotspot drops.
    Hold BOOT at power-on for the phone setup page (Wi-Fi "WishBand-admin", pw wishband123).

  PN532 wiring (DIP switches: SEL0 = OFF, SEL1 = ON for I2C)
    VCC -> 3V3 (or 5V)   GND -> GND   SDA -> GPIO 21   SCL -> GPIO 22
  Buzzer (+) -> GPIO 4   LED (+) -> GPIO 2

  Libraries: "Adafruit PN532" (Library Manager). Copy secrets.example.h to secrets.h.
  =============================================================================
*/

#define FW_VERSION "2.0.0"

#include <WiFi.h>
#include <HTTPClient.h>
#include <WiFiClientSecure.h>
#include <Wire.h>
#include <Adafruit_PN532.h>

#if __has_include("secrets.h")
  #include "secrets.h"
#else
  #warning "secrets.h not found: using secrets.example.h (copy it to secrets.h and fill in your Wi-Fi)"
  #include "secrets.example.h"
#endif
#include "wifi_setup.h"

#define SDA_PIN    21
#define SCL_PIN    22
#define BUZZER_PIN 4
#define LED_PIN    2

Adafruit_PN532 nfc(SDA_PIN, SCL_PIN);
const char* WIFI_SSIDS[] = WIFI_SSID_LIST;
const int WIFI_COUNT = sizeof(WIFI_SSIDS) / sizeof(WIFI_SSIDS[0]);

String lastUid = "";
unsigned long lastTapAt = 0;
const unsigned long DEBOUNCE_MS = 2500;
String serialQueued = "";            // from "W:" command
unsigned long lastHeartbeat = 0;

const int MAX_CONTENT = 100;         // fits NTAG213 (144 bytes user memory)

// ---------------------------------------------------------------- sounds
void beep(int f, int ms) { tone(BUZZER_PIN, f, ms); delay(ms + 20); }
void soundOk()    { digitalWrite(LED_PIN, HIGH); beep(2200, 110); beep(2900, 170); digitalWrite(LED_PIN, LOW); }
void soundRead()  { digitalWrite(LED_PIN, HIGH); beep(2600, 70); digitalWrite(LED_PIN, LOW); }
void soundError() { digitalWrite(LED_PIN, HIGH); beep(700, 380); digitalWrite(LED_PIN, LOW); }

// ---------------------------------------------------------------- Wi-Fi
void setupWifi() {
  for (int i = 0; i < WIFI_COUNT; i++) WifiSetup::addBuiltIn(WIFI_SSIDS[i], WIFI_PASSWORD);
  WifiSetup::begin("WishBand-admin");
}

bool ensureWifi() { return WifiSetup::loop(); }

// ---------------------------------------------------------------- HTTP
int request(const char* method, const String& path, const String& body, String& response) {
  String url = String(SERVER_URL) + path;
  HTTPClient http;
  WiFiClientSecure secure;
  if (url.startsWith("https://")) { secure.setInsecure(); http.begin(secure, url); }
  else { http.begin(url); }
  http.setTimeout(6000);
  http.addHeader("Content-Type", "application/json");
  if (strlen(STATION_KEY) > 0) http.addHeader("X-Station-Key", STATION_KEY);
  int code = strcmp(method, "GET") == 0 ? http.GET() : http.POST(body);
  response = code > 0 ? http.getString() : http.errorToString(code);
  http.end();
  return code;
}

// Minimal JSON string reader: returns value of "key":"value", or "" for null/missing.
String jsonString(const String& json, const String& key) {
  int k = json.indexOf("\"" + key + "\":");
  if (k < 0) return "";
  int start = json.indexOf('"', k + key.length() + 3);
  int nullAt = json.indexOf("null", k + key.length() + 3);
  if (start < 0 || (nullAt >= 0 && nullAt < start)) return "";
  String out = "";
  for (int i = start + 1; i < (int)json.length(); i++) {
    char c = json[i];
    if (c == '\\' && i + 1 < (int)json.length()) { out += json[++i]; continue; }
    if (c == '"') break;
    out += c;
  }
  return out;
}

String jsonEscape(const String& s) {
  String o = s;
  o.replace("\\", "\\\\");
  o.replace("\"", "\\\"");
  return o;
}

// ---------------------------------------------------------------- NTAG read / write
String readNtagContent() {
  uint8_t buffer[160];
  memset(buffer, 0, sizeof(buffer));
  bool readAny = false;
  for (uint8_t page = 4; page < 40; page++) {
    uint8_t data[4];
    if (!nfc.ntag2xx_ReadPage(page, data)) break;
    readAny = true;
    memcpy(&buffer[(page - 4) * 4], data, 4);
  }
  if (!readAny) return "(could not read)";

  if (buffer[0] == 0x03 && buffer[2] == 0xD1) {
    uint8_t payloadLen = buffer[4];
    if (buffer[5] == 0x55) {                         // URI record
      const char* prefixes[] = { "", "http://www.", "https://www.", "http://", "https://" };
      String url = buffer[6] <= 4 ? prefixes[buffer[6]] : "";
      for (int i = 1; i < payloadLen && 6 + i < (int)sizeof(buffer); i++) url += (char)buffer[6 + i];
      return url;
    }
    if (buffer[5] == 0x54) {                         // Text record
      uint8_t langLen = buffer[6] & 0x1F;
      String text = "";
      for (int i = 1 + langLen; i < payloadLen && 6 + i < (int)sizeof(buffer); i++) text += (char)buffer[6 + i];
      return text;
    }
  }
  String raw = "";
  for (int i = 0; i < 80; i++) if (buffer[i] >= 32 && buffer[i] <= 126) raw += (char)buffer[i];
  return raw.length() ? raw : "(blank tag)";
}
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

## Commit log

2026-09-03 feat: Jeju AuraBeads zero-power NFC ecosystem, multi-station firmware, and Vercel cloud deployment
2026-09-03 feat: Add Vercel HTTPS support to ESP32 firmware and smart cloud polling
2026-09-03 chore: Point ESP32 firmware to live production domain https://smart-nfc-bracelet.vercel.app
2026-09-04 fix: Improve SPI initialization and boost antenna gain to MAX on MFRC522
2026-09-08 fix: explicit RST pulse and 2MHz SPI clock in RC522 diagnostic
    [test_rc522_diagnostic.ino]
2026-09-08 feat: max RF driver power and WUPA wake-up detection for NTAG215 stickers
2026-09-30 feat: food/place/activity stations, dual Wi-Fi firmware and Jeju-style app
    - firmware: admin (PN532), food, place, activity sketches; WiFiMulti joins
    BUNDAOBUNTAI or OhmPatumwan and reconnects; Wi-Fi kept in git-ignored secrets.h;
    offline tap queue, heartbeats, new-stamp / voucher / duplicate sounds
    - server: shared lib/ (core rules, routes, store with v1 migration, live UV)
    used by both server.js and api/index.js; station registry drives stamps and
    the voucher rule; AI picks, Helping Map, SOS flow, last-location log,
    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
2026-10-02 feat(web): SOS tab, maps on For You and Stamps, UX polish
    - floating SOS button replaced by an SOS tab (hold-to-send, live status,
    hotlines, Helping Map, help near you with call + directions)
    - For You opens with a map of the current picks; tap a card to fly to its pin,
    category chips stay pinned while scrolling, UV advice strip, ranked cards
    - Stamps opens with the route map (stamped vs next stop) and a next-stop card
    - Leaflet bundled locally in public/vendor so maps load without a CDN
    - loading skeletons, UV pill in the header, bead card on Me, nav SOS badge
2026-10-04 feat: Supabase database option and simpler first-visit flow
    - lib/store.js: Supabase (Postgres) store when SUPABASE_URL and
    SUPABASE_SERVICE_ROLE_KEY are set, JSON file otherwise; writes only
    changed rows, refreshes before each API call so Vercel instances agree
    - supabase/schema.sql: tourists and sos_alerts tables, RLS on, read-only
    views for check-ins, location log and recommendation events
    - For You: one-tap diet card on first visit, stamp progress strip that
    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
2026-10-04 feat: 3D models for wristband and check-in station
    Printable STLs (Hallabong NFC charm, basalt and UV beads, station base and lid),
    renders, A3 dimensioned drawings and parametric Python source.
    [station_base.stl, station_lid.stl, wristband_basalt_bead.stl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]
2026-10-04 fix: keep API paths through Vercel rewrite, pin Node 22, live DB health check
    - vercel.json passes the original path as __path and lib/app.js restores
    it, so routes work whether Vercel hands Express the original or the
    rewritten URL (the new rewrite warning)
    - engines.node pinned to 22.x (no surprise major upgrades)
    - /api/health now reads the database and reports ok, row counts or the
    Supabase error; SUPABASE_URL tolerates a trailing /rest/v1 or spaces
    - server.js exports the server for Vercel's Express preset
2026-10-04 feat(admin): demo control for mock data, journey steps and clean-up
    - Load full demo story: 11 wish-bands at every stage (fresh, 1-2 stamps,
    voucher ready, voucher used, SOS pending / dispatched / resolved) with
    back-dated taps and AI pick events so every metric has numbers
    - Play one band's journey: AI pick opened, place/food/activity taps,
    finish route, redeem voucher, move GPS, send SOS, reset band
    - Clean up: clear SOS alerts, reset all stamps, remove empty guest bands,
    download a JSON backup, delete everything (type DELETE to confirm)
    - Header chip shows whether data is in Supabase or the local file
2026-10-04 feat: 3D enclosures for the admin desk unit and check-in station
    Drop the wristband parts. Add a sloped admin desk unit (ESP32 + PN532,
    wristband tray) next to the check-in station, with new renders and
    A3 dimensioned drawings for both devices.
    [admin_bottom_plate.stl, admin_shell.stl, station_lid.stl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]
2026-10-04 feat: live weather picks, road route, languages, dark mode, any-nationality profile
    - Live Jeju weather (UV, temperature, rain, wind) from Open-Meteo feeds
    the AI picks: rain and strong wind push exposed spots down, cards say why
    - Stamps map draws the route along real roads (saved route.json, OSRM
    foot routing, or straight lines); npm run build-route saves it
    - SOS: Korean hotlines incl. 1345, plus the tourist's embassy or Jeju
    consulate from their nationality via a live map search
    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
2026-10-07 Adapt teammate's mockup: real venues, place details, today's interests
    - Real Jeju venues with VisitJeju/VisitKorea pages from the team's research:
    Hyeopjae Beach, Jeolmul Forest, Hallim Park, Haenyeo Museum, Gimnyeong
    Maze Park, Warda (halal), Dasoni and Loving Hut (vegan), replacing the
    made-up halal and vegan sample restaurants.
    - Cards link to the official tourism page when there is no own website.
    - Tap a card for a details sheet: photo, address, why it was picked,
    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
2026-10-21 Field trial kit, local impact panel and 5-tap band SOS
    - Trial: consent sheet (TRIAL_MODE=true), 3-question survey, trial bands counted
    apart from demo data; admin export of the four advisor indicators (CSV/JSON,
    participant codes only)
    - Impact panel: check-ins and AI picks at local businesses and quiet spots vs
    hotspots; merchant picks the shop when redeeming, redemptions per shop
    - SOS without a phone: 5 taps of the same band within 12 s at any station.
    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
2026-10-22 Add support-free admin shell (admin_shell_flat.stl)
    Same fit as admin_shell.stl, but the tray ring, NFC waves, LED ring and
    pebbles are engraved and the band stop lip is removed, so the shell
    prints flat on its top with no supports. The original file is kept.
2026-10-22 docs: solder ESP32 wires; cradle has no clip
2026-10-22 Add one stamp station sketch for food, place and activity
    firmware/stamp replaces the three copies in firmware/food, place and
    activity. Each board is told which station it is with "station <id>"
    in the Serial Monitor or on the phone setup page; the id is saved in
    flash. The LED blinks the station number at power-on. wifi_setup.h
    gains optional hooks for extra setup-page sections.
2026-10-24 Lower Wi-Fi transmit power to stop brownout resets
    The Wi-Fi start-up current spike tripped the ESP32 brownout detector on
    a station running a PN532. wifi_setup.h now starts Wi-Fi at 15 dBm
    (WIFI_TX_POWER, overridable in secrets.h). README gains a brownout
    troubleshooting note.
2026-10-25 Set language from nationality and space phone numbers per country
    Picking a nationality switches the app to that country's language when the
    app has it (English otherwise), unless a language was picked by hand.
    Phone numbers are spaced as typed using a per-country pattern, and saved
    in that format.
2026-10-28 Save the tourist profile with the band in the database
    Any phone that opens a band now loads its profile from the server, so a
    second phone does not ask to register again.
    - POST /api/tourist/:uid/profile saves the profile fields on the band;
    /profile/delete removes them (stamps and voucher stay).
    - Phones that set up a band before this upload their saved copy once.
    - The phone keeps a cached copy; a copy the server no longer has is dropped.
    - Public band list and live feed still leave the profile out.
    - Band 5-tap SOS now carries the saved profile.
    - Replaces the copy-by-QR flow from the previous commit.
2026-10-28 Make the app fit every screen: small phones, notches, tablets, desktop, dark mode
    - Admin desk no longer runs off the side on phones; wish-band table turns into cards
    - Small phones: Go button gets its own full-width row, category tabs never overflow
    - Tablets and computers: wider layout, two-column picks, floating tab bar, centred sheets
    - Notch and home bar space when added to the home screen
    - Dark mode follows the phone setting until picked by hand; admin desk too
    - Dark mode fixes: unreadable selected tab, rank badges, toasts
    - Bigger tap targets, keyboard focus rings, reduced motion respected
2026-10-28 Add Vietnamese, Indonesian and Malay; keep long labels on screen
    - Three new app languages (all texts, machine translated); nationality
    Vietnam -> Tiếng Việt, Indonesia -> Bahasa Indonesia, Malaysia and
    Brunei -> Bahasa Melayu
    - Category tabs wrap between words instead of running off screen
    - Reason chips, the deposit chip and stamp names wrap in long languages
    - Checked every tab in all 14 languages at 280 to 820 px wide
